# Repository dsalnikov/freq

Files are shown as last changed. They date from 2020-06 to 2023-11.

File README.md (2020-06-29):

# This is a KiCad project of ESC power board 

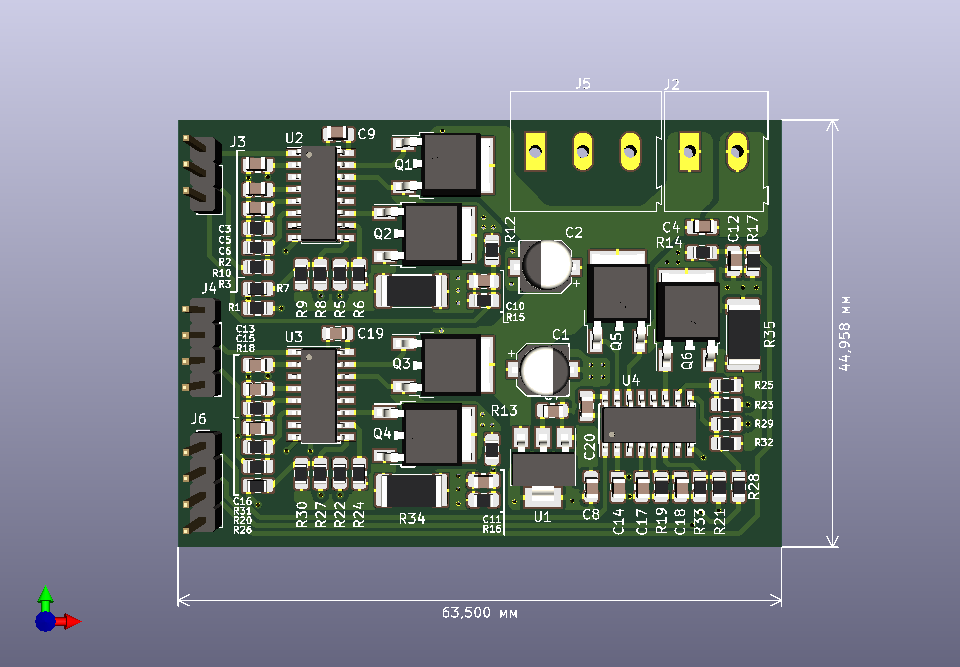
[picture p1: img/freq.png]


This is a board with power MOSFETs (any TO-252), drivers (L6390), and measurement circuits for current and voltage. 
All components are quite big, so board can be hand soldered.

### Known issues:
* There is no input voltage measurement
* Input voltage capacitors are too small

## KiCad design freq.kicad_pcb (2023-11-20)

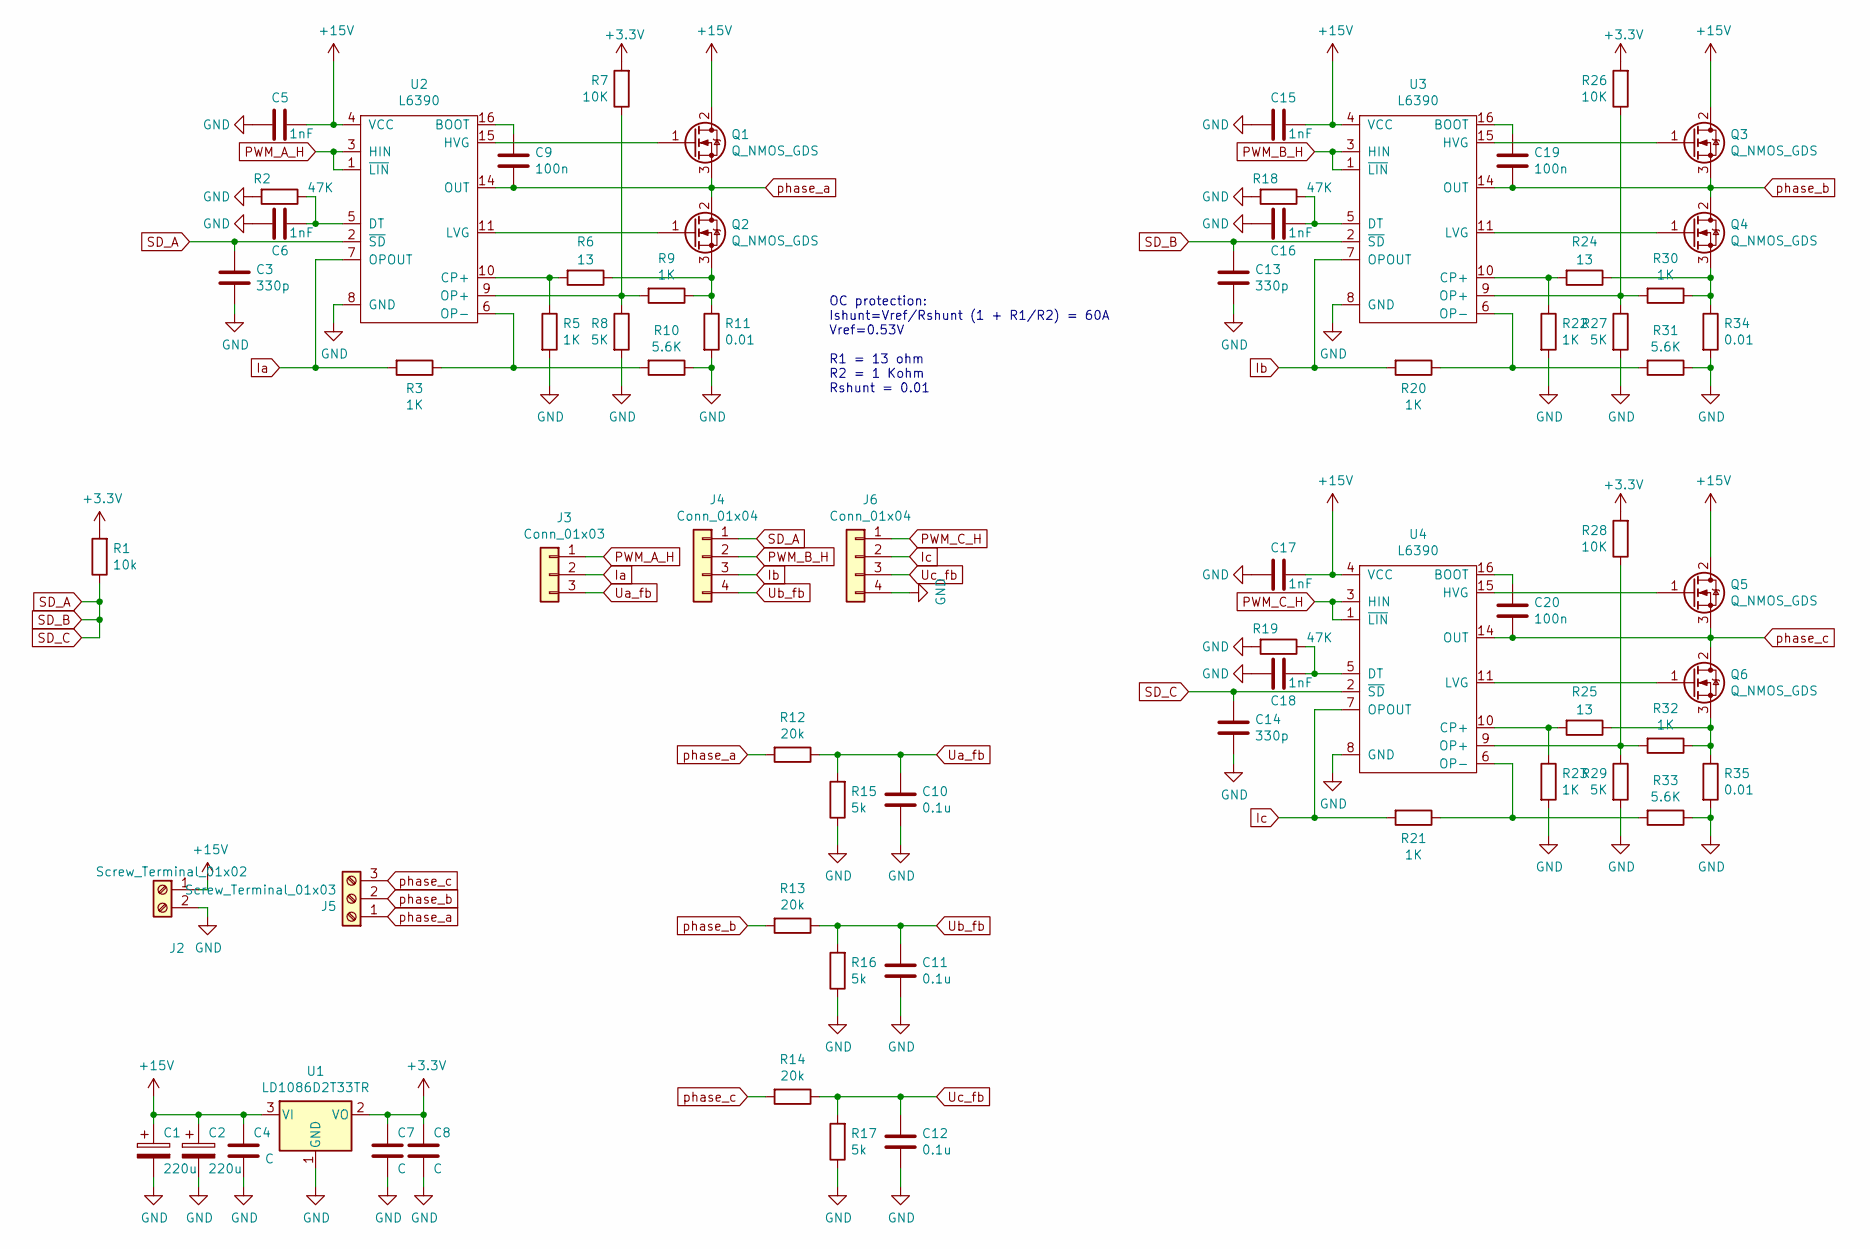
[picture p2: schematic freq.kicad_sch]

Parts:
C1, C2: 220u; CP_Elec_5x4.5
C3, C13, C14: 330p; C_0805_2012Metric_Pad1.15x1.40mm_HandSolder
C4, C7, C8: C; C_0805_2012Metric_Pad1.15x1.40mm_HandSolder
C5, C6, C15, C16, C17, C18: 1nF; C_0805_2012Metric_Pad1.15x1.40mm_HandSolder
C9, C19, C20: 100n; C_0805_2012Metric_Pad1.15x1.40mm_HandSolder
C10, C11, C12: 0.1u; C_0805_2012Metric_Pad1.15x1.40mm_HandSolder
J2: Screw_Terminal_01x02; TerminalBlock_Altech_AK300-2_P5.00mm
J3: Conn_01x03; PinHeader_1x03_P2.54mm_Vertical
J4, J6: Conn_01x04; PinHeader_1x04_P2.54mm_Vertical
J5: Screw_Terminal_01x03; TerminalBlock_Altech_AK300-3_P5.00mm
Q1, Q2, Q3, Q4, Q5, Q6: Q_NMOS_GDS; TO-252-2
R1: 10k; R_0805_2012Metric_Pad1.15x1.40mm_HandSolder
R2, R18, R19: 47K; R_0805_2012Metric_Pad1.15x1.40mm_HandSolder
R3, R5, R9, R20, R21, R22, R23, R30, R32: 1K; R_0805_2012Metric_Pad1.15x1.40mm_HandSolder
R6, R24, R25: 13; R_0805_2012Metric_Pad1.15x1.40mm_HandSolder
R7, R26, R28: 10K; R_0805_2012Metric_Pad1.15x1.40mm_HandSolder
R8, R27, R29: 5K; R_0805_2012Metric_Pad1.15x1.40mm_HandSolder
R10, R31, R33: 5.6K; R_0805_2012Metric_Pad1.15x1.40mm_HandSolder
R11, R34, R35: 0.01; R_2512_6332Metric_Pad1.52x3.35mm_HandSolder
R12, R13, R14: 20k; R_0805_2012Metric_Pad1.15x1.40mm_HandSolder
R15, R16, R17: 5k; R_0805_2012Metric_Pad1.15x1.40mm_HandSolder
U1: LD1086D2T33TR; SOT-223-3_TabPin2
U2, U3, U4: L6390; SOIC-16_3.9x9.9mm_P1.27mm

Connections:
+3V3: C7.1, C8.1, R1.2, R7.2, R26.2, R28.2, U1.2 (VO)
+15V: C1.1, C2.1, C4.1, C5.1, C15.1, C17.1, J2.1, Q1.2 (D), Q3.2 (D), Q5.2 (D), U1.3 (VI), U2.4 (VCC), U3.4 (VCC), U4.4 (VCC)
GND: C1.2, C2.2, C3.2, C4.2, C5.2, C6.2, C7.2, C8.2, C10.2, C11.2, C12.2, C13.2, C14.2, C15.2, C16.2, C17.2, C18.2, J2.2, J6.4, R2.2, R5.2, R8.2, R10.1, R11.2, R15.1, R16.1, R17.1, R18.2, R19.2, R22.2, R23.2, R27.2, R29.2, R31.1, R33.1, R34.2, R35.2, U1.1 (GND), U2.8 (GND), U3.8 (GND), U4.8 (GND)
Ia: J3.2, R3.2, U2.7 (OPOUT)
Ib: J4.3, R20.2, U3.7 (OPOUT)
Ic: J6.2, R21.2, U4.7 (OPOUT)
unnamed: C6.1, R2.1, U2.5 (DT)
unnamed: C9.1, U2.16 (BOOT)
unnamed: C16.1, R18.1, U3.5 (DT)
unnamed: C18.1, R19.1, U4.5 (DT)
unnamed: C19.1, U3.16 (BOOT)
unnamed: C20.1, U4.16 (BOOT)
unnamed: Q1.1 (G), U2.15 (HVG)
unnamed: Q2.1 (G), U2.11 (LVG)
unnamed: Q2.3 (S), R6.1, R9.1, R11.1
unnamed: Q3.1 (G), U3.15 (HVG)
unnamed: Q4.1 (G), U3.11 (LVG)
unnamed: Q4.3 (S), R24.1, R30.1, R34.1
unnamed: Q5.1 (G), U4.15 (HVG)
unnamed: Q6.1 (G), U4.11 (LVG)
unnamed: Q6.3 (S), R25.1, R32.1, R35.1
unnamed: R5.1, R6.2, U2.10 (CP+)
unnamed: R7.1, R8.1, R9.2, U2.9 (OP+)
unnamed: R3.1, R10.2, U2.6 (OP-)
unnamed: R20.1, R31.2, U3.6 (OP-)
unnamed: R21.1, R33.2, U4.6 (OP-)
unnamed: R22.1, R24.2, U3.10 (CP+)
unnamed: R23.1, R25.2, U4.10 (CP+)
unnamed: R26.1, R27.1, R30.2, U3.9 (OP+)
unnamed: R28.1, R29.1, R32.2, U4.9 (OP+)
PWM_A_H: J3.1, U2.1 (~LIN), U2.3 (HIN)
PWM_B_H: J4.2, U3.1 (~LIN), U3.3 (HIN)
PWM_C_H: J6.1, U4.1 (~LIN), U4.3 (HIN)
SD_A: C3.1, C13.1, C14.1, J4.1, R1.1, U2.2 (~SD), U3.2 (~SD), U4.2 (~SD)
Ua_fb: C10.1, J3.3, R12.1, R15.2
Ub_fb: C11.1, J4.4, R13.1, R16.2
Uc_fb: C12.1, J6.3, R14.1, R17.2
phase_a: C9.2, J5.1, Q1.3 (S), Q2.2 (D), R12.2, U2.14 (OUT)
phase_b: C19.2, J5.2, Q3.3 (S), Q4.2 (D), R13.2, U3.14 (OUT)
phase_c: C20.2, J5.3, Q5.3 (S), Q6.2 (D), R14.2, U4.14 (OUT)

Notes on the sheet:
OC protection: Ishunt=Vref/Rshunt (1 + R1/R2) = 60A Vref=0.53V R1 = 13 ohm R2 = 1 Kohm Rshunt = 0.01

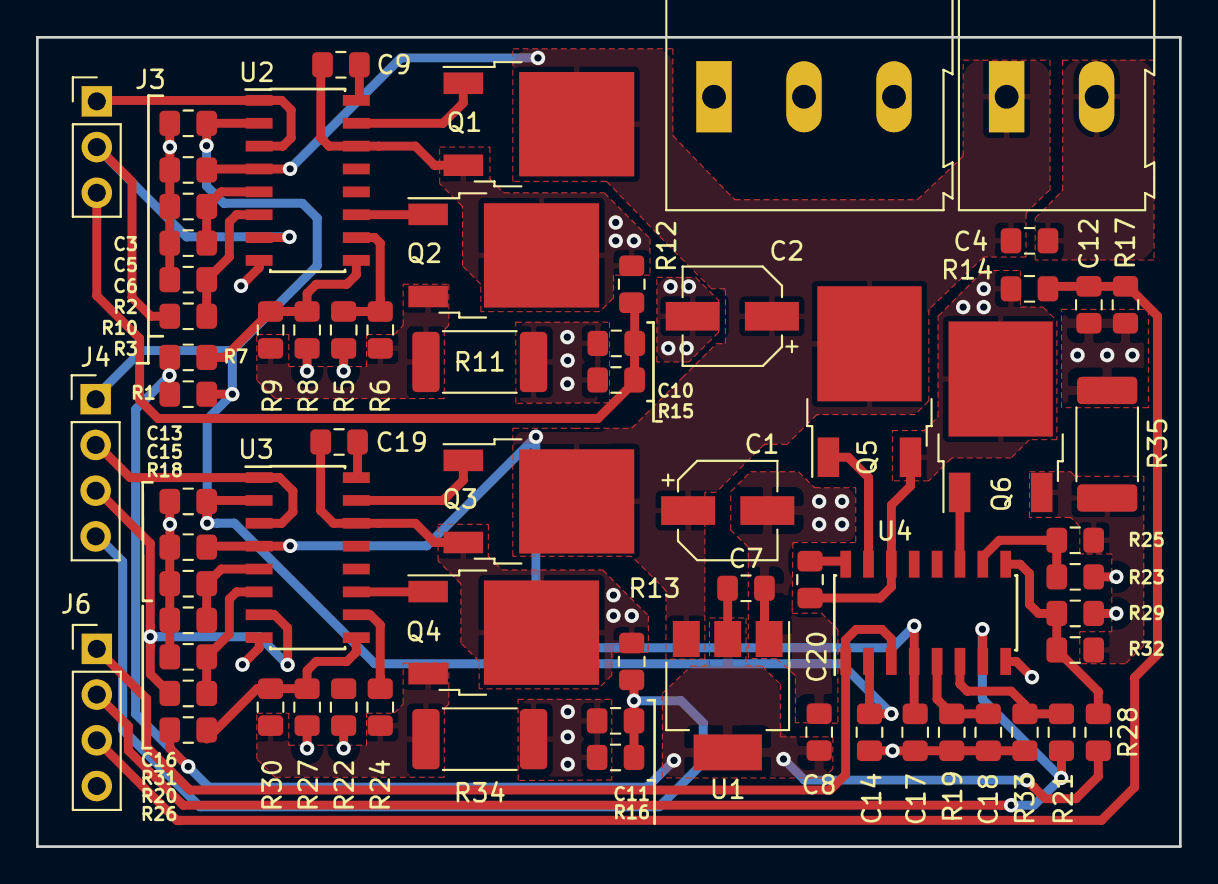
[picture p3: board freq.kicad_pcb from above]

Board: 2 copper layers, 63.5 x 45.0 mm, 69 parts (0 on the bottom side), 40 nets.

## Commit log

2020-06-29 uploaded project files
    [freq.kicad_pcb, freq.sch]
2023-11-20 update kicad version
    [freq.kicad_pcb, freq.kicad_sch]
2023-11-20 add kicad-rescue symbols
    [freq.kicad_sch]
